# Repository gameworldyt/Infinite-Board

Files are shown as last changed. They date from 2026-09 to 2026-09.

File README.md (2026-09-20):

# Infinite-Board
A Project for Hack Club HackPad. This is a the Infinite Boards Repo for me to use for daily and gameing. I am also using this project to learn coding and new skills. Also  Thanks to Hack Club for giving me this opurtunity.

**What Is the Infinite Pad?** 
Infinite Pad is a project I have been working on to submit to hack club hack pad mission. This pad can be used for gaming or work use as it has a lot of functions.

**How many keys?**
There are 12 keys with different fetures on each one. 

**What does it use?**
It uses 
Part,Quantity,Used For
XIAO RP2040,1,Microcontroller
1N4148 through-hole diode,12,Key matrix
MX-style mechanical switch,12,Keys
2-pin rotary encoder,0,Not used
0.91-inch OLED display,1,Startup display
DSA keycap,12,Keycaps
SK6812 MINI-E,0,Not used
M3 x 16mm screw,4,Case assembly
M3 x 5 x 4mm heat-set insert,4,Case screw mounting
3D printed case,1,Enclosure
PCB,1,Custom 2-layer PCB

**What is the OLED for?**
It is used for displaying text. Also It displays if the Pad is redy to be used and if it is working.

**Why you wanted a macro pad**
I wanted to make a macro pad because I would like to learn new skills and make hardware.

**Why you designed your own instead of using an existing one**
Because I wanted to learn new skills and not copy others. 

**What makes your design different/useful** 
It is also easy to use and easy for the hand to tap each button.

| Key | Function |
| --- | --- |
| 1 | Ctrl + Windows + Right |
| 2 | R |
| 3 | Mute / Unmute |
| 4 | T |
| 5 | Open File Explorer |
| 6 | Windows Key |
| 7 | Enter |
| 8 | 8 |
| 9 | 9 |
| 10  | Close current window |
| 11  | Alt + Tab |
| 12  | E |







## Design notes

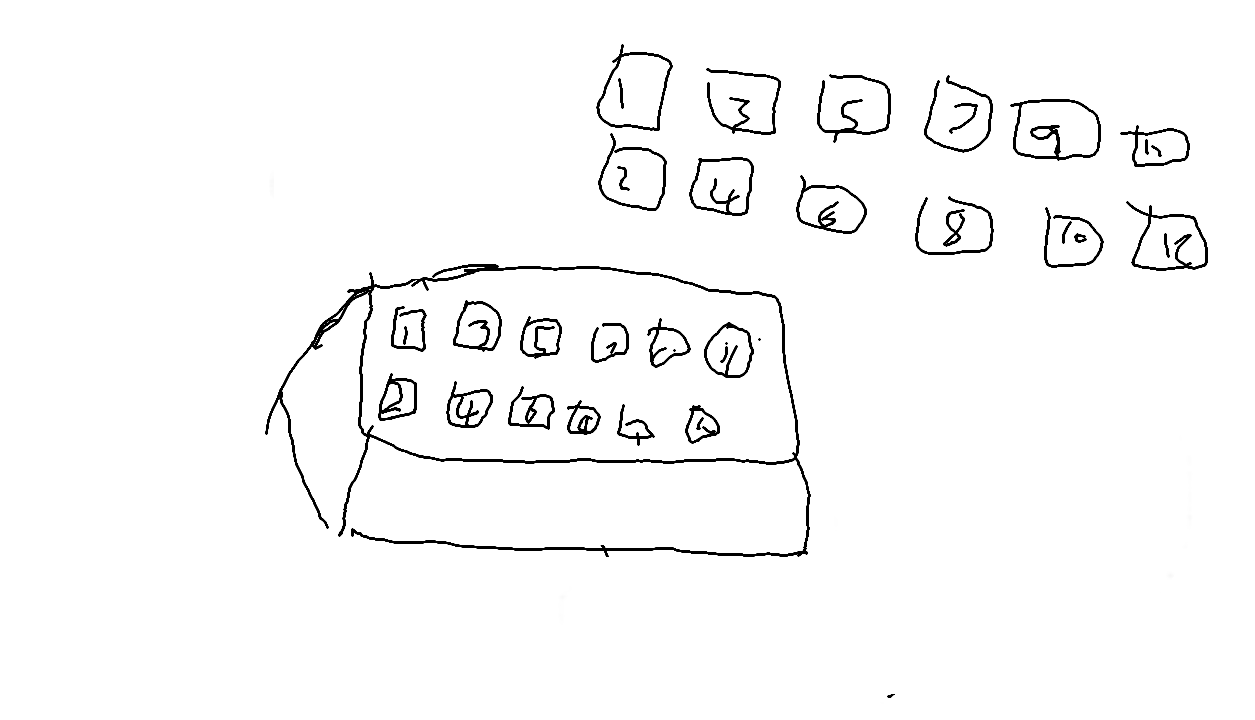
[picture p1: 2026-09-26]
Design.png

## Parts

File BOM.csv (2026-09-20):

# USED
 | Component | Qty used | Source
 | ------------------------------ | -------: | ---------------------------------------------------------------------------------------------------------------------------------------------------
 | Seeed Studio XIAO RP2040 | 1 | [Seeed Studio XIAO RP2040](https://www.seeedstudio.com/XIAO-RP2040-with-Pre-Soldered-RP2040-4MB-Flash-MCU-Board-p-6328.html
 | MX-style mechanical switches | 12 | **Hack Club kit**
 | 1N4148 through-hole diodes | 12 | **Hack Club kit**
 | 0.91" 128×32 OLED | 1 | **Hack Club kit**
 | DSA keycaps | 12 | **Hack Club kit**
 | M3 × 16 mm screws | 4 | **Hack Club kit**
 | M3 × 5 × 4 mm heat-set inserts | 4 | **Hack Club kit**
 | Custom 2-layer PCB | 1 | Fabricated using Hack Club PCB grant
 | 3D-printed case — TopShell | 1 | Printing Legion / 3D printed
 | 3D-printed case — BottomShell | 1 | Printing Legion / 3D printed
# NOT USED
 | Component | Kit quantity | Used
 | -------------------- | -----------: | ----:
 | MX-style switches | 16 | 12
 | 1N4148 diodes | 20 | 12
 | EC11 rotary encoders | 2 | **0**
 | DSA keycaps | 16 | 12
 | SK6812 MINI-E LEDs | 16 | **0**
# CSV FORMAT
Component,Quantity,Source,Link,Notes
Seeed Studio XIAO RP2040,1,Seeed Studio,https://www.seeedstudio.com/XIAO-RP2040-with-Pre-Soldered-RP2040-4MB-Flash-MCU-Board-p-6328.html,Main MCU
MX-style mechanical switch,12,Hack Club Kit,,12 of 16 supplied
1N4148 through-hole diode,12,Hack Club Kit,,12 of 20 supplied
0.91 inch OLED display,1,Hack Club Kit,,GND-VCC-SCL-SDA
DSA keycap,12,Hack Club Kit,,12 of 16 supplied
M3 x 16mm screw,4,Hack Club Kit,,Case assembly
M3 x 5 x 4mm heat-set insert,4,Hack Club Kit,,Case mounting
Custom 2-layer PCB,1,PCB manufacturer,,97x67mm
3D printed TopShell,1,Printing Legion,,Case
3D printed BottomShell,1,Printing Legion,,Case

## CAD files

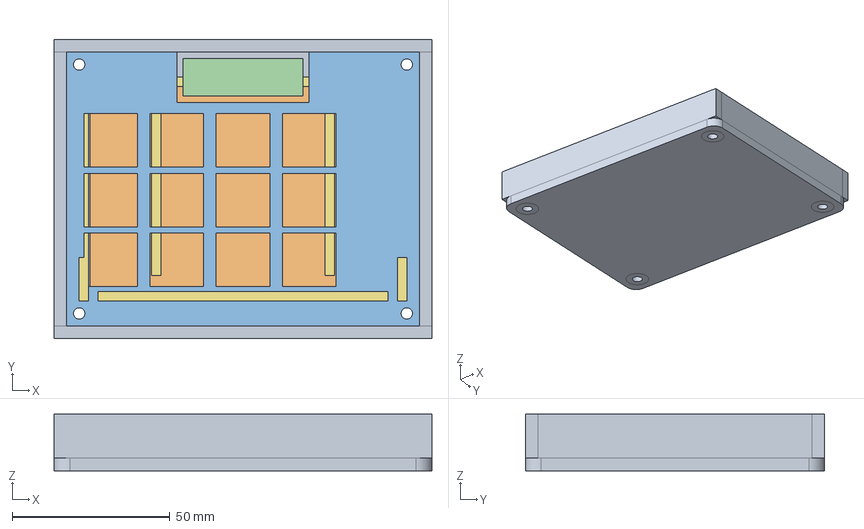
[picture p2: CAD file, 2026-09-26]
CAD/Infinite Pad.FCStd
120.0 x 95.0 x 18.0 mm
BottomShell
PCB
TopShell
OLED
LocatingPins
PCBSupports
StructuralRibs

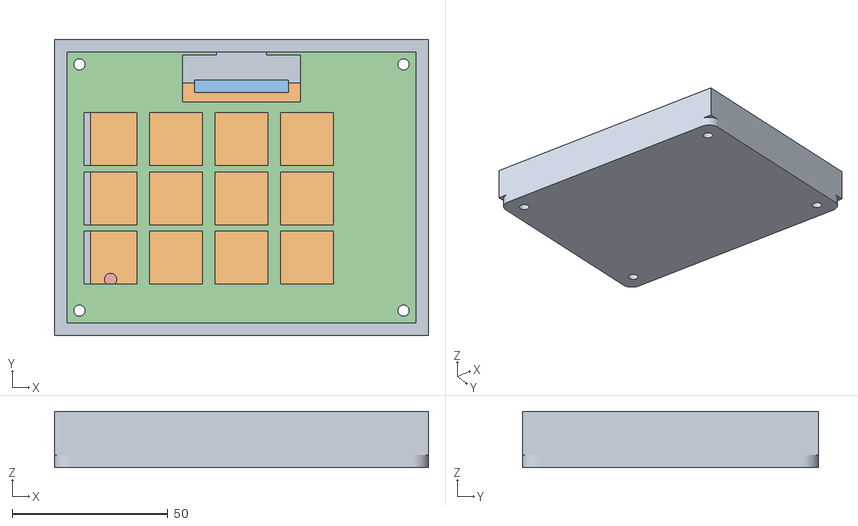
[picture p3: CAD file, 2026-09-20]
CAD/Test inf pad.obj
120.0 x 95.0 x 18.0
BottomShell
PCB
OLED
TopShell
LocatingPins

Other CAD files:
Production/STEP/InfinitePad.step

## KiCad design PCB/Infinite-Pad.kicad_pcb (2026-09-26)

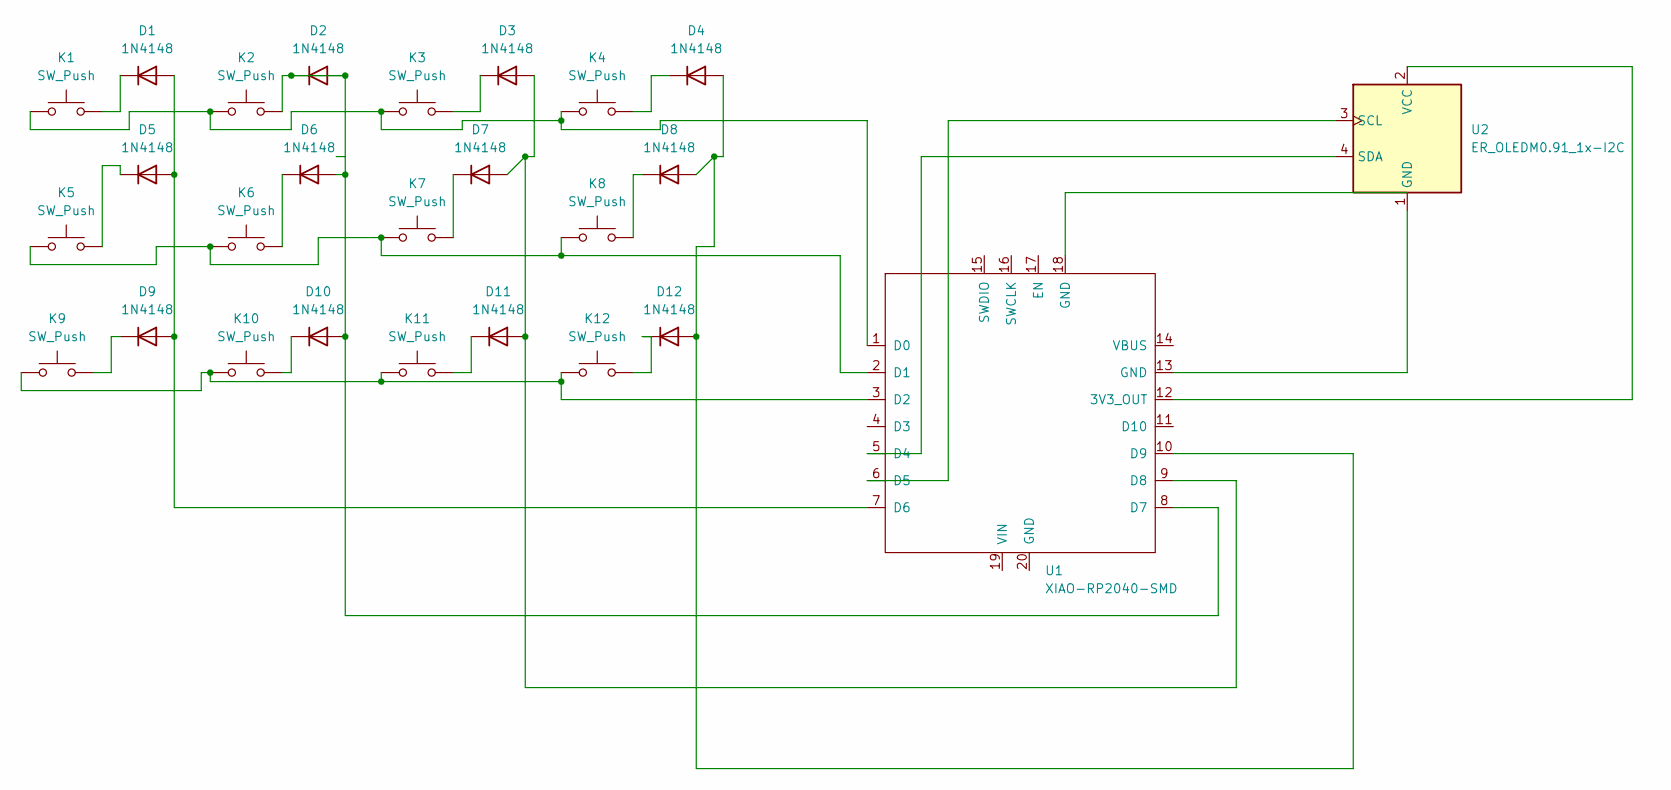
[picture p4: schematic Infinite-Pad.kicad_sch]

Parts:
D1, D2, D3, D4, D5, D6, D7, D8, D9, D10, D11, D12: 1N4148; D_DO-35_SOD27_P7.62mm_Horizontal
K1, K2, K3, K4, K5, K6, K7, K8, K9, K10, K11, K12: SW_Push; Nidec_Copal_CAS-120A
U1: XIAO-RP2040-SMD
U2: ER_OLEDM0.91_1x-I2C

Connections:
unnamed: D1.2 (A), D5.2 (A), D9.2 (A), U1.7 (D6)
unnamed: D1.1 (K), K1.2
unnamed: D3.1 (K), K3.2
unnamed: D4.1 (K), K4.2
unnamed: D5.1 (K), K5.2
unnamed: D6.1 (K), K6.2
unnamed: D7.1 (K), K7.2
unnamed: D8.1 (K), K8.2
unnamed: D9.1 (K), K9.2
unnamed: D2.1 (K), D2.2 (A), D6.2 (A), D10.2 (A), K2.2, U1.8 (D7)
unnamed: D10.1 (K), K10.2
unnamed: D3.2 (A), D7.2 (A), D11.2 (A), U1.9 (D8)
unnamed: D11.1 (K), K11.2
unnamed: D4.2 (A), D8.2 (A), D12.2 (A), U1.10 (D9)
unnamed: D12.1 (K), K12.2
unnamed: U1.12 (3V3_OUT), U2.2 (VCC)
unnamed: K1.1, K2.1, K3.1, K4.1, U1.1 (D0)
unnamed: K5.1, K6.1, K7.1, K8.1, U1.2 (D1)
unnamed: K9.1, K10.1, K11.1, K12.1, U1.3 (D2)
unnamed: U1.5 (D4), U2.4 (SDA)
unnamed: U1.6 (D5), U2.3 (SCL)
unnamed: U1.13 (GND), U2.1 (GND)

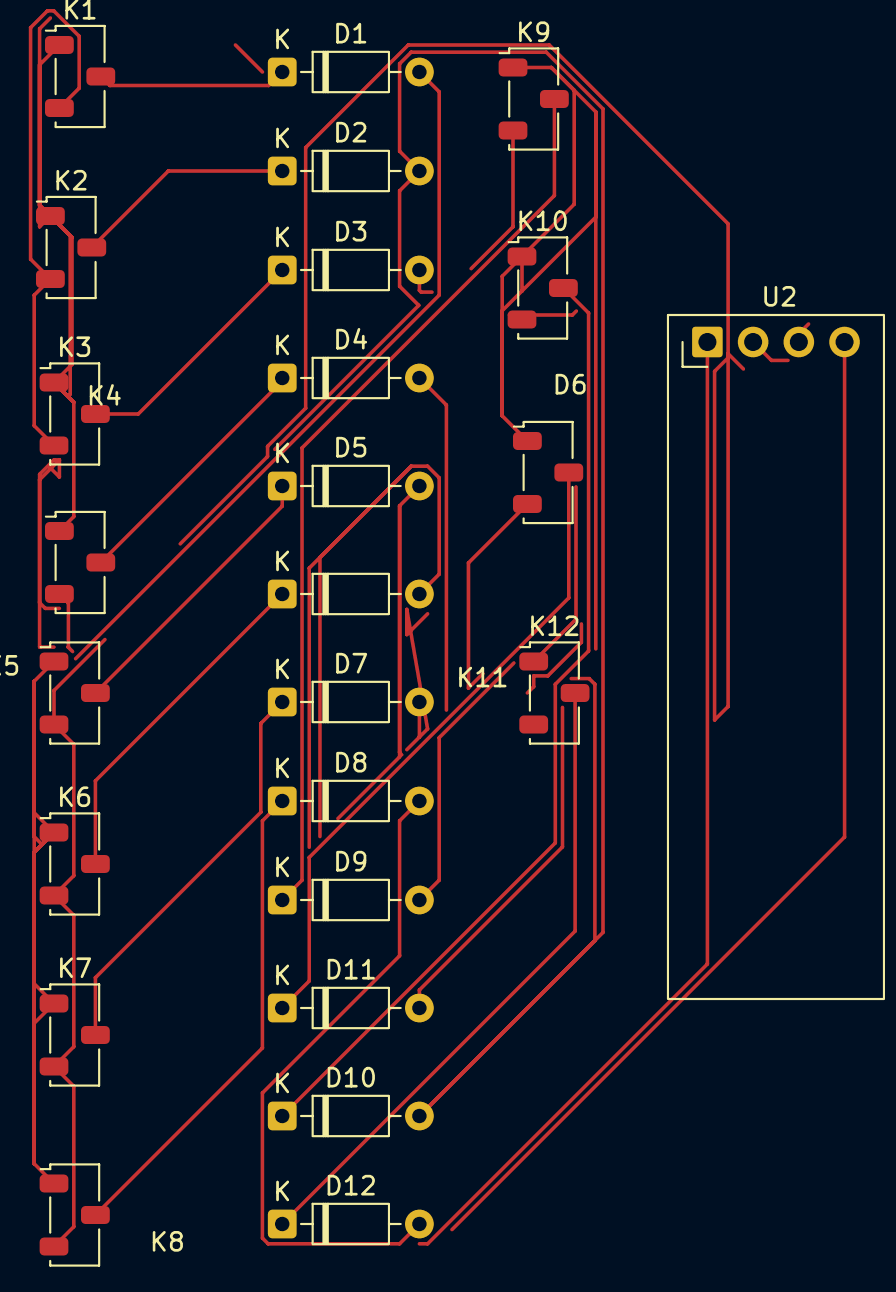
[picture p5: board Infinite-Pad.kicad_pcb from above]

Board: 2 copper layers, 25 parts (0 on the bottom side), 18 nets.

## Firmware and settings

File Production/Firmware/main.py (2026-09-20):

import board
import busio
import adafruit_ssd1306

from kmk.kmk_keyboard import KMKKeyboard
from kmk.scanners import DiodeOrientation
from kmk.keys import KC
from kmk.modules.macros import Macros, Press, Release, Tap



keyboard = KMKKeyboard()

macros = Macros()
keyboard.modules.append(macros)



i2c = busio.I2C(board.D5, board.D4)

oled = adafruit_ssd1306.SSD1306_I2C(128, 32, i2c)

oled.fill(0)
oled.text("INFINITE PAD", 0, 0, 1)
oled.text("READY", 0, 16, 1)
oled.show()




keyboard.row_pins = (
    board.D0,
    board.D1,
    board.D2, 
)

keyboard.col_pins = (
    board.D6,
    board.D7,
    board.D8,
    board.D9,
)

keyboard.diode_orientation = DiodeOrientation.COL2ROW




FILE_EXPLORER = KC.MACRO(
    Press(KC.LGUI),
    Tap(KC.E),
    Release(KC.LGUI),
)

CLOSE_WINDOW = KC.MACRO(
    Press(KC.LALT),
    Tap(KC.F4),
    Release(KC.LALT),
)

ALT_TAB = KC.MACRO(
    Press(KC.LALT),
    Tap(KC.TAB),
    Release(KC.LALT),
)

NEXT_DESKTOP = KC.MACRO(
    Press(KC.LCTRL),
    Press(KC.LGUI),
    Tap(KC.RIGHT),
    Release(KC.LGUI),
    Release(KC.LCTRL),
)


MUTE_UNMUTE = KC.MUTE




keyboard.keymap = [
    [
        NEXT_DESKTOP,       # K1
        KC.R,               # K2
        MUTE_UNMUTE,        # K3
        KC.T,               # K4

        FILE_EXPLORER,      # K5
        KC.LGUI,             # K6
        KC.ENTER,            # K7
        KC.N8,               # K8

        KC.N9,               # K9
        CLOSE_WINDOW,        # K10
        ALT_TAB,             # K11
        KC.E,                # K12
    ]
]



if __name__ == '__main__':
    keyboard.go()

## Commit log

2026-09-20 ADDED CAD COMPLETED TECHINA
    [InfinitePad.step, Test inf pad.obj]
2026-09-20 Add components and quantities to BOM.csv
    Updated BOM.csv with additional components and quantities.
    [BOM.csv]
2026-09-26 Organize Infinite Pad project files
    [Infinite Pad.FCStd, Infinite-Pad.kicad_pcb, Infinite-Pad.kicad_sch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]
